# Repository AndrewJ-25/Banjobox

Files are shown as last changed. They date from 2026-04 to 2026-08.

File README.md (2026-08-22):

# Banjobox

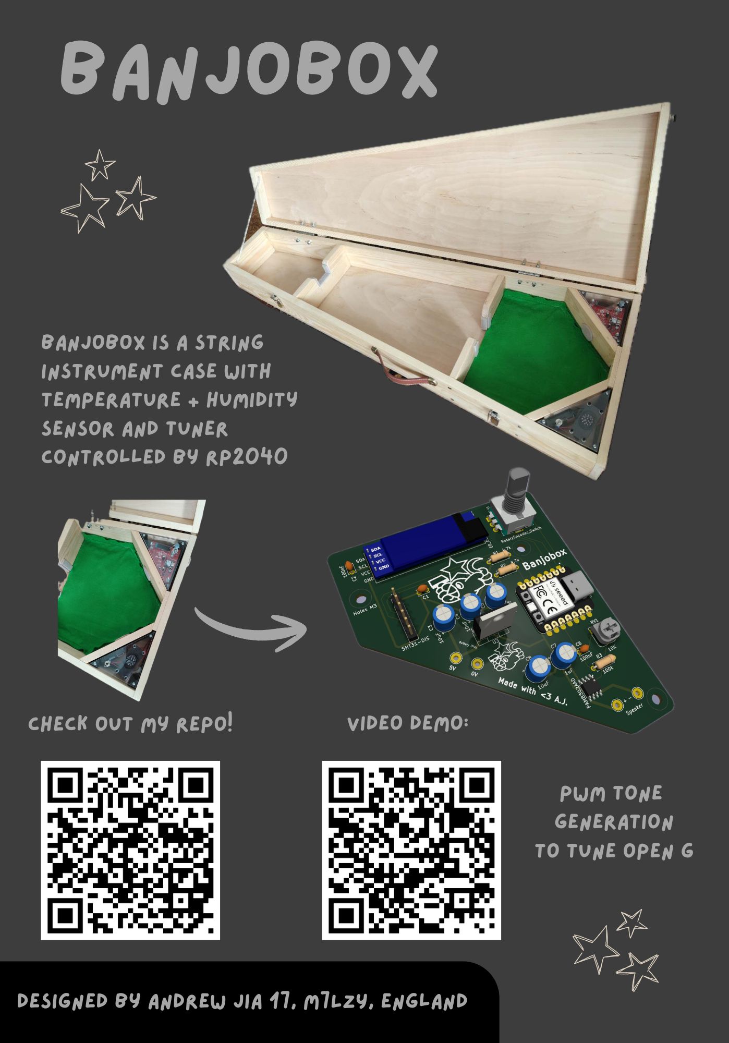
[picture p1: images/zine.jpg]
Zine


Banjobox is a banjo case with a built in tuner and temperature/ humidity sensor. I designed it to store a mountain banjo I made but the case can be modified to accomodate other string instruments.

Purchasing a banjo case is difficult, especially as shape varies a lot. Banjobox is low cost (plywood, softwood timber) and super customiseable!

Banjobox features a Seeed Studios Xiao RP2040 running MicroPython. UI consists of a rotary encoder and 0.91" OLED display. You can select different notes to be played through the speaker to tune your banjo.

Pressing the rotary encoder button switches between monitor mode and tune mode. Monitor mode displays temperature and humidity readings. Tune mode plays a square wave. Turning the knob changes the note played.

Files for 3D printing and laser cutting can be found in the OnShape project linked below.

### Demo
https://www.youtube.com/watch?v=Ie8TWf3fN2Y

### Features
 - Seeed Studios Xiao RP2040
 - SHT31 temp + humidity sensor
 - PAM8302 Class-D amp with 3W 4ohm speaker
 - Powered by 3x AA batteries
 - 0.91 inch OLED display
 - EC11 rotary encoder

## OnShape project
https://cad.onshape.com/documents/49037cb32e4fd0c851c4d81b/w/99bbea41b70cb909ece41dd4/e/4da4cdf8e8884e6941d1b422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

## Schematic
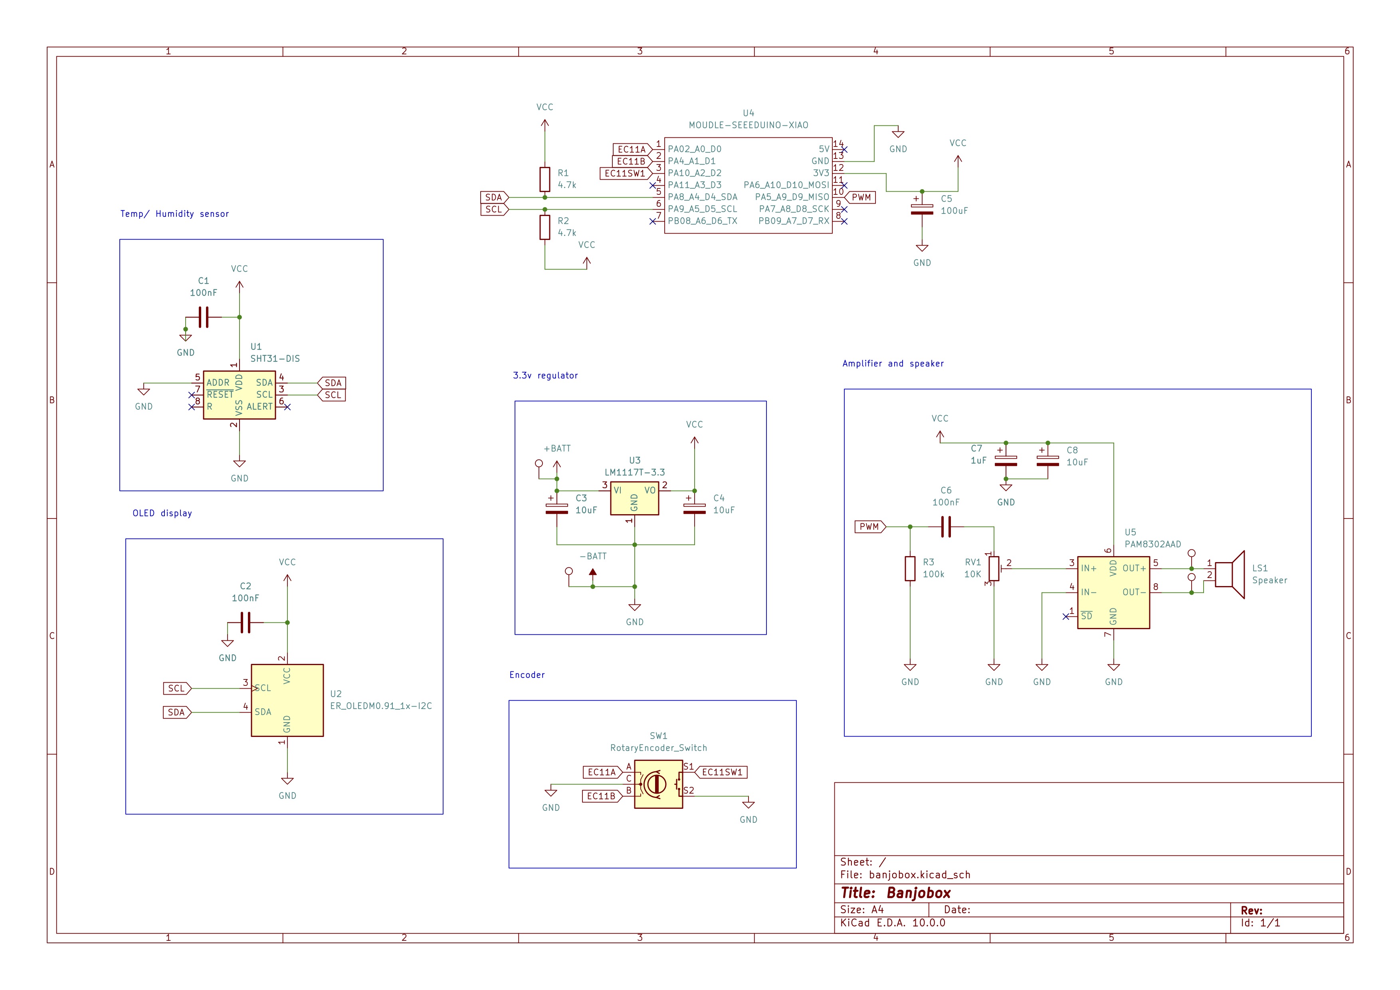
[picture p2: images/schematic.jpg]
Schematic


## Case construction tips
Construction of the case requires minimal woodworking skills and tools. I reccomend using some wood screws rather than relying on glue alone. A full set of plans can be found in the production folder.

### General
 - Add felt padding where appropriate (including this in the CAD model was impractical). The green blocks on the lid can be made by wrapping foam with felt.
   
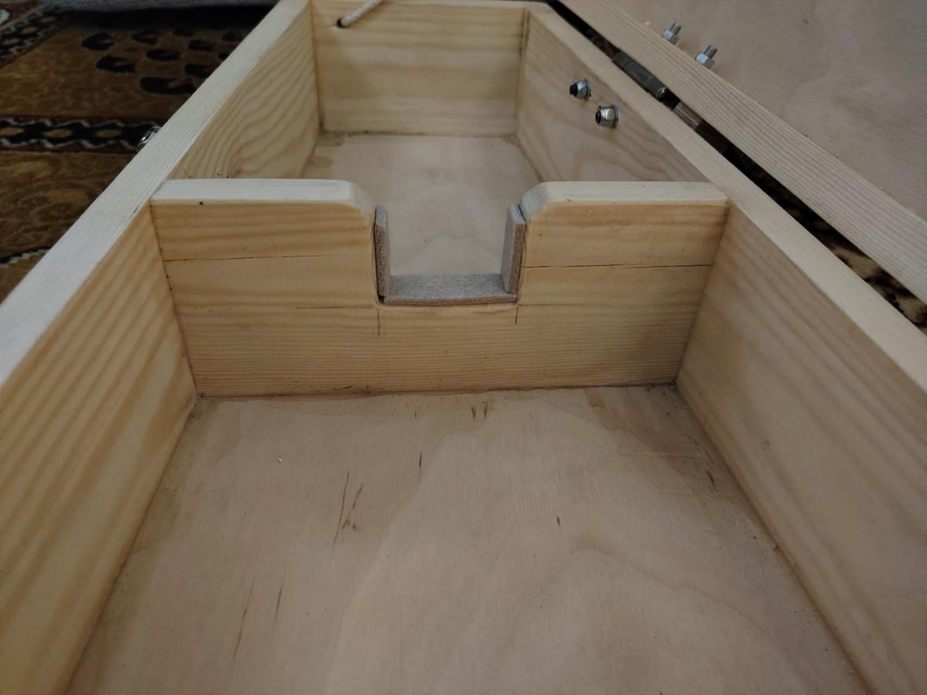
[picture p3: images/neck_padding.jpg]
padding
   
 - Heel supports can be reinforced with metal brackets or dowels
 - Remember to cut holes to run wires!
 - Hold battery holder in place with velcro.
 - SHT31 breakout board to be fixed inside battery compartment with sticky foam. Speaker vents will ensure good airflow.
 - Electronics parts are held in place by two acrylic covers. Use long M3 bolts or threaded rod to mount the PCB.

### 3D printing
 - The PCB cover and speaker/ battery cover are each supported by three 3D printed columns
 - Use M3 heatset inserts
 - Glue in place

### Laser cutting
 - Laser cut PCB and spekeaker/ battery covers from clear acrylic
 - Recommended 4mm but exact thickness is unimportant

Remember to cut wire holes in the side supports! See below:
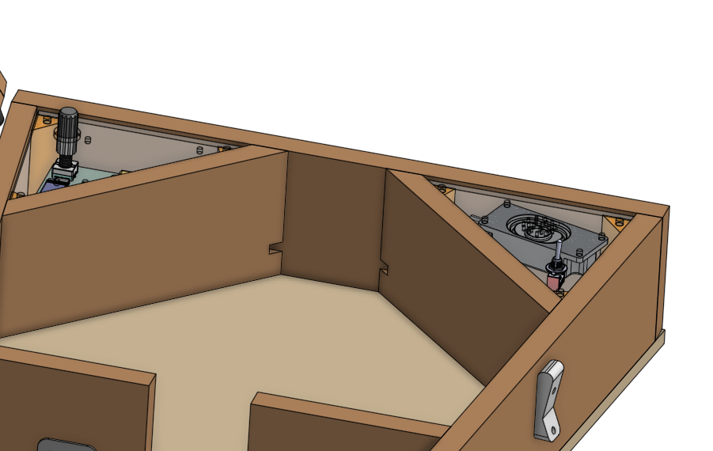
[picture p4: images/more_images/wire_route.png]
Wire run


### Note regarding PCB
- In the final product, the external voltage regulator and accompanying capacitors were omitted in favour of the XIAO's onboard voltage regulator.

## Images
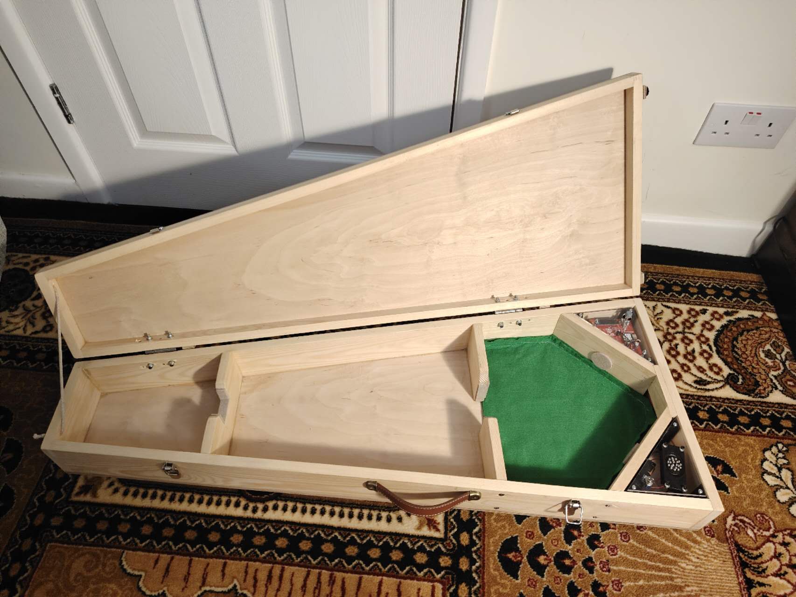
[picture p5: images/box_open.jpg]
banjobox

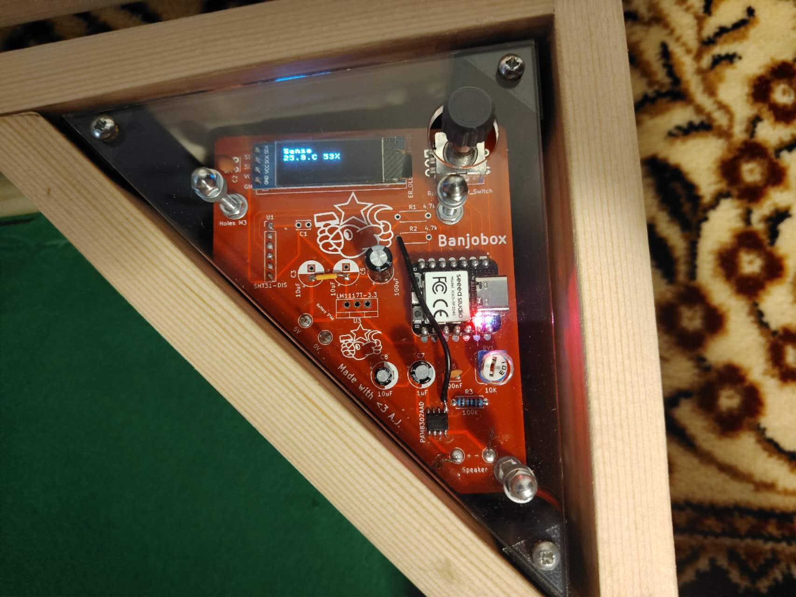
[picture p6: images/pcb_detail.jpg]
pcb

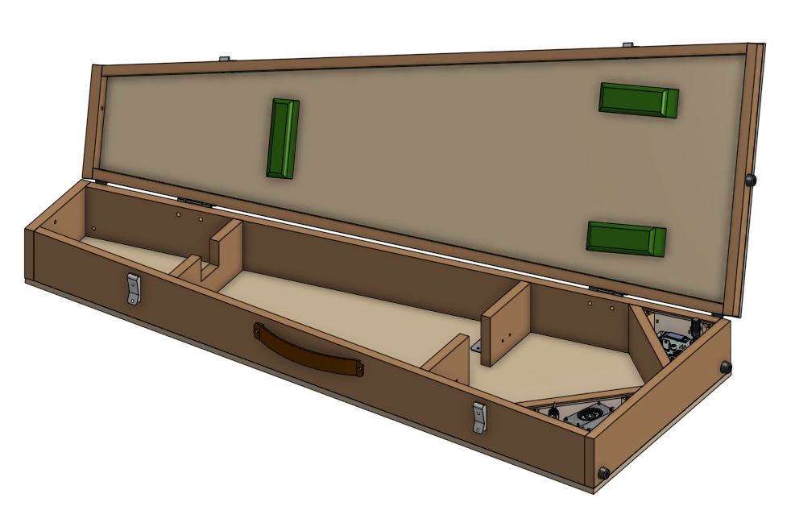
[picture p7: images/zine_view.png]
render

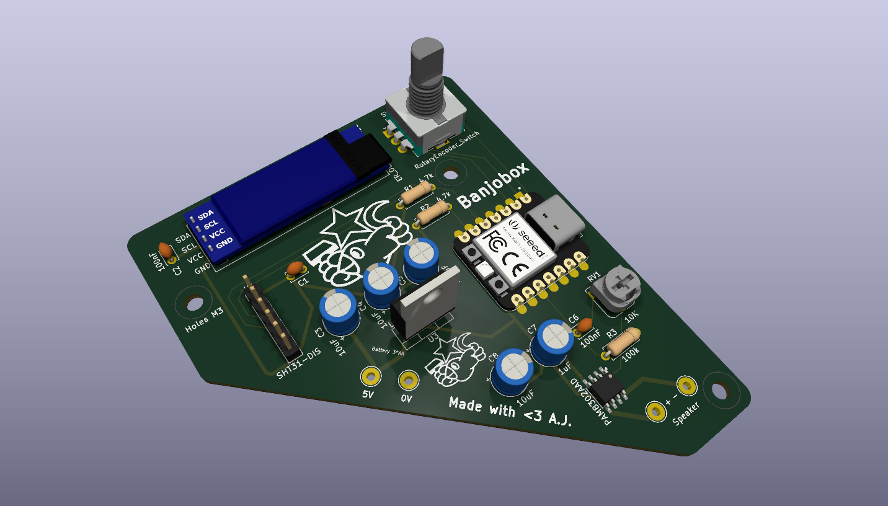
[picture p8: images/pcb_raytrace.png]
prcb render


## BOM
NOTE: Links are suggestions only. Some parts are ubiquitous and purchasing online would be impractical not to mention expensive. I'm from the UK hence some links might not work if you live overseas. Prices may vary.
| Quantity | Item | Cost/£ | Link |
|---|---|---|---|
| 1 | Seeed Studios Xiao RP2040 | 3.90 | https://thepihut.com/products/seeed-xiao-rp2040 |
| 1 | PCB | 5.00 | https://jlcpcb.com/ |
| 1 | 0.91 inch OLED | 3.80 | https://www.aliexpress.com/item/1005006365845676.html |
| 1 | SHT31 breakout board | 1.57 | https://www.aliexpress.com/item/32695064184.html |
| - | Components | 10.00 | https://www.digikey.co.uk/ |
| 1 | 3W speaker | 3.40 | https://thepihut.com/products/mono-enclosed-speaker-3w-4-ohm |
| 1 | Toggle switch | 1.67 | https://www.digikey.co.uk/en/products/detail/cit-relay-and-switch/ANT11SEBQE/12503360 |
| 1 | 3xAA battery holder | 1.99 | https://www.ebay.co.uk/itm/358406972409?_skw=3+x+aa+battery+holder |
| 6 | 3D printed parts | 2.00 | https://jlcpcb.com/ |
| 2 | laser-cut acrylic | 0.50 | https://jlcpcb.com/ |
| 6 | Heatset insert | 2.89 | https://www.ebay.co.uk/itm/314297471901 |
| 13 | M3 screw | 7.59 | https://www.ebay.co.uk/itm/305743217020 |
| 7 | M3 nut | 3.38 | https://www.ebay.co.uk/itm/167673257973 |
| - | Wood screws | 7.74 | https://www.ebay.co.uk/itm/277661008745?_skw=wood+screws |
| - | 15mm timber | 16.00 | https://www.homedepot.com/p/Waddell-Project-Board-24-in-x-4-in-x-0-5-in-Unfinished-S4S-Poplar-Hardwood-w-No-Finger-Joints-Ideal-for-DIY-Shelving-PB19418/329189316 |
| 1 | Plywood 9mm | 30.00  | https://www.ebay.co.uk/itm/257438787345?_skw=9mm+plywood |
| 2 | Hinges | 1.97 | https://www.ebay.co.uk/itm/222426341432 |
| 2 | Hook and latch | 3.60 | https://www.ebay.co.uk/itm/168179187930 |
| 1 | Handle | 4.20 | https://www.ebay.co.uk/itm/306436283287 |
| 11 | Rubber feet | 3.29 | https://www.ebay.co.uk/itm/173200464234 |
| - | Foam padding | 10.99  | https://www.ebay.co.uk/itm/112490209816 |
| - | Felt padding | 6.25 | https://www.ebay.co.uk/itm/188091406494 |
|TOTAL: | | 131.73 | |

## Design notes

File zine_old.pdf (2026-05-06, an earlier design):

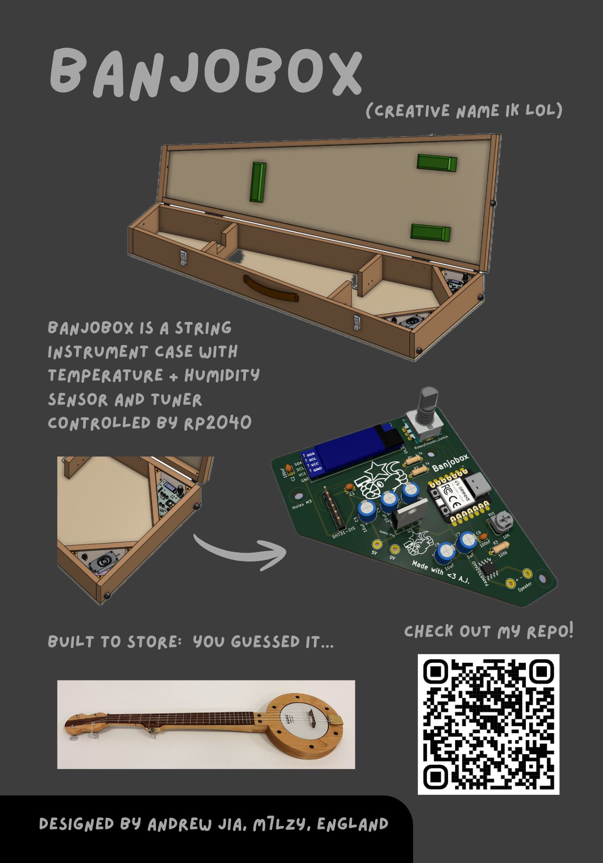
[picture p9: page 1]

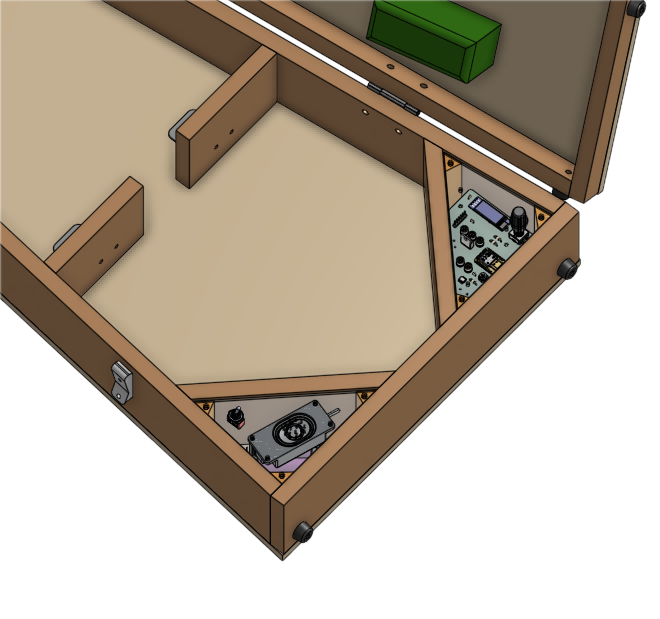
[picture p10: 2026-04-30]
images/more_images/zine_detail Background Removed.png

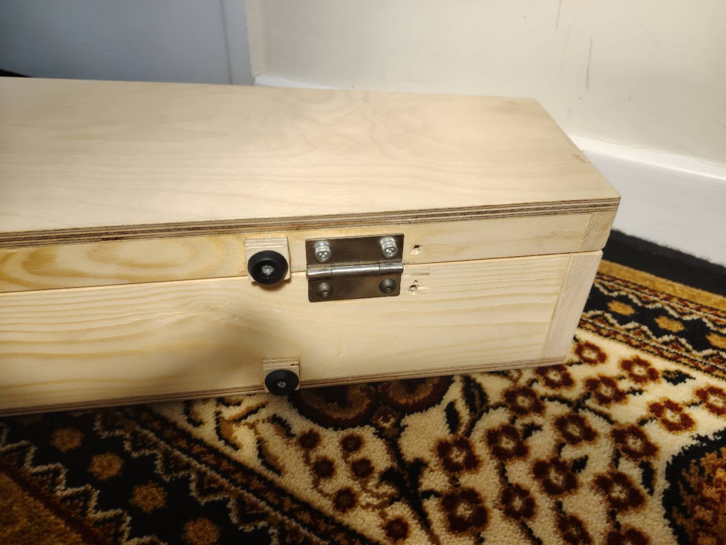
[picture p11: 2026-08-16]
images/hinge.jpg

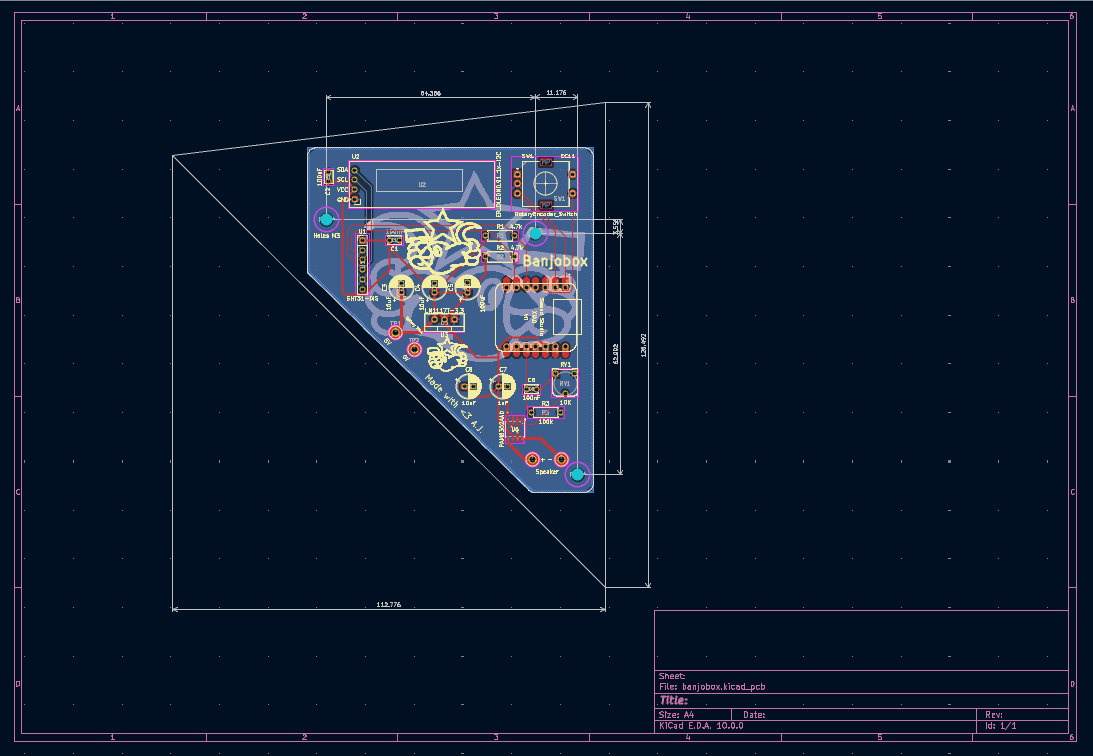
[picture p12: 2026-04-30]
images/banjobox_pcb.png

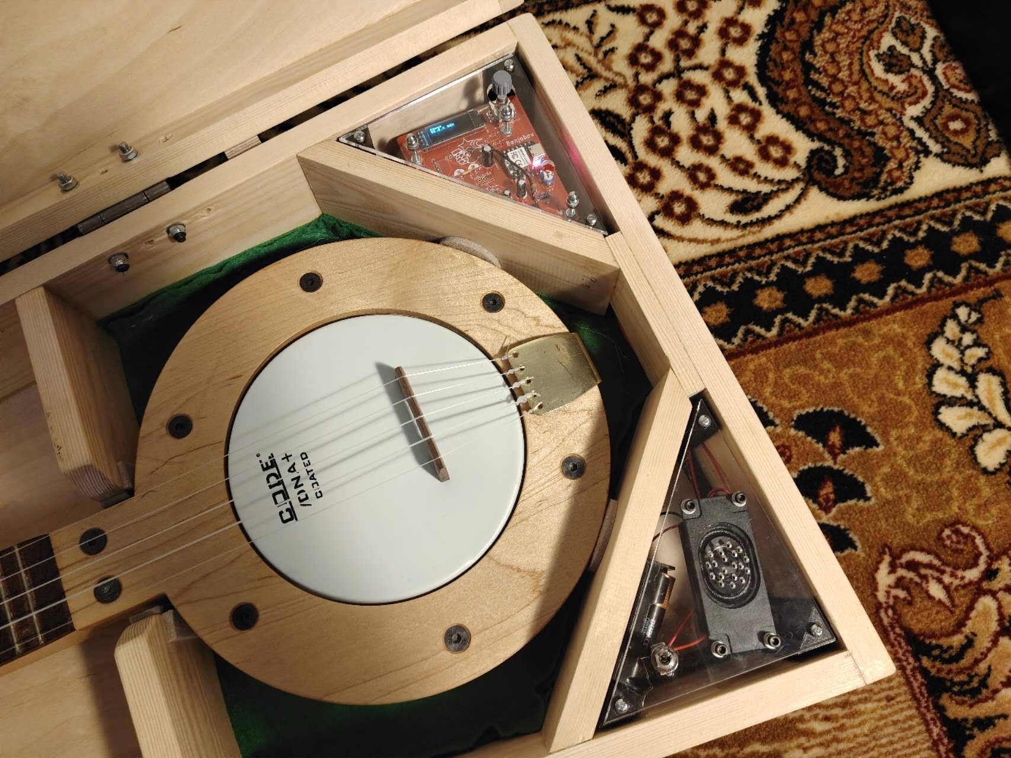
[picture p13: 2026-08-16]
images/banjo_body.jpg

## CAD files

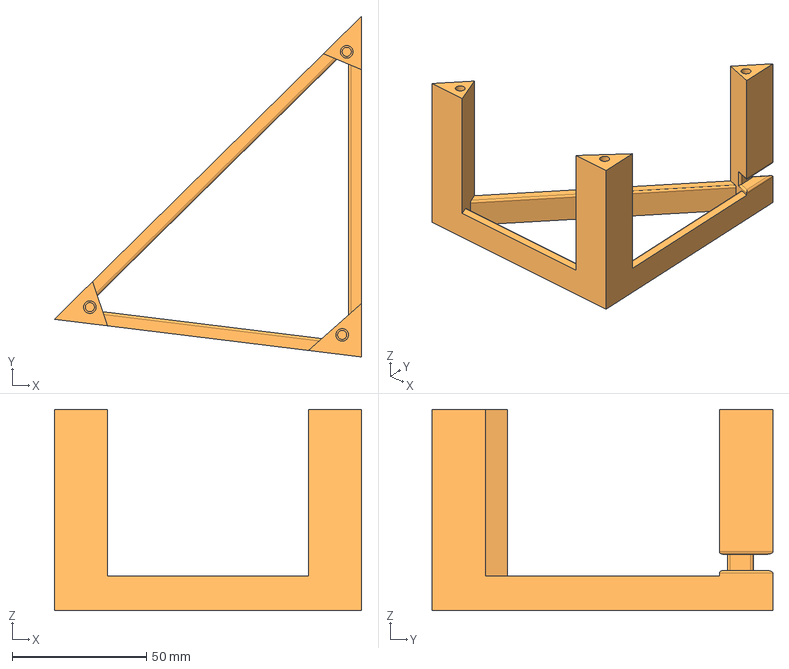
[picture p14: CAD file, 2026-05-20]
production/3d_print/step/speaker_cover_mounts.step
114.4 x 126.9 x 75.0 mm

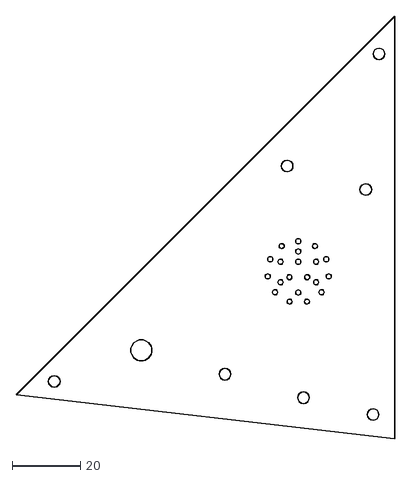
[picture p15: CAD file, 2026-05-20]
production/acrylic/dxf/speaker_cover.dxf
110.5 x 123.4

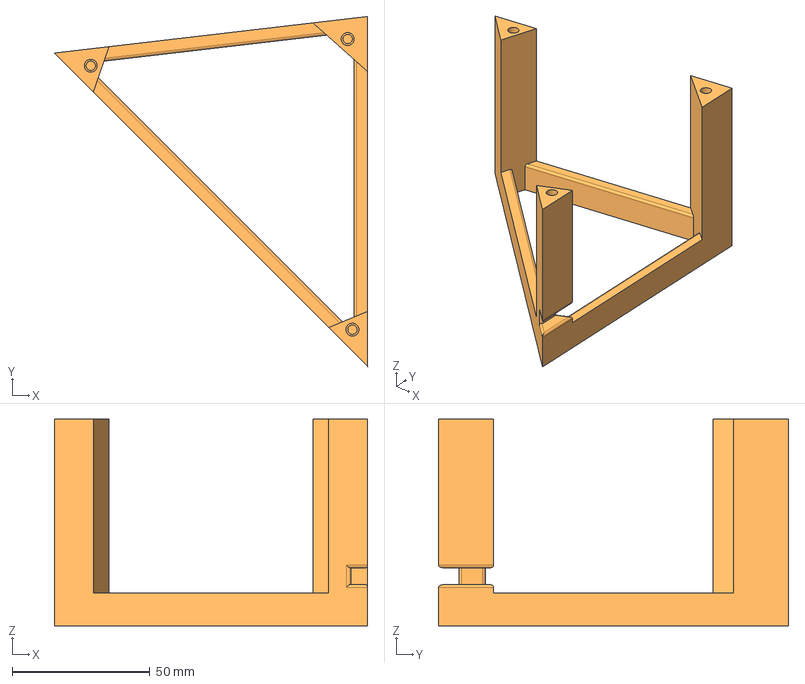
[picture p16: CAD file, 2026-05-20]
production/3d_print/step/pcb_cover_mounts.step
113.7 x 126.9 x 75.0 mm

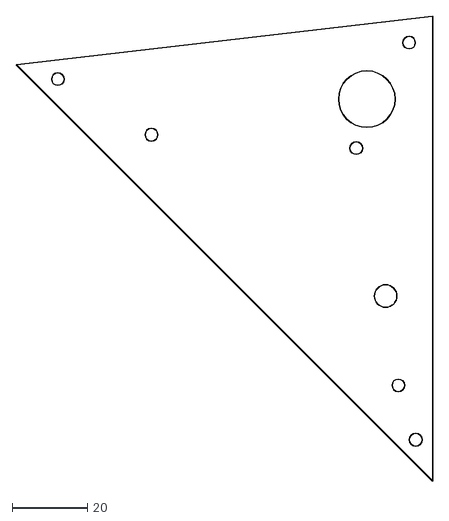
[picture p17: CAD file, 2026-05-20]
production/acrylic/dxf/pcb_cover.dxf
110.5 x 123.4

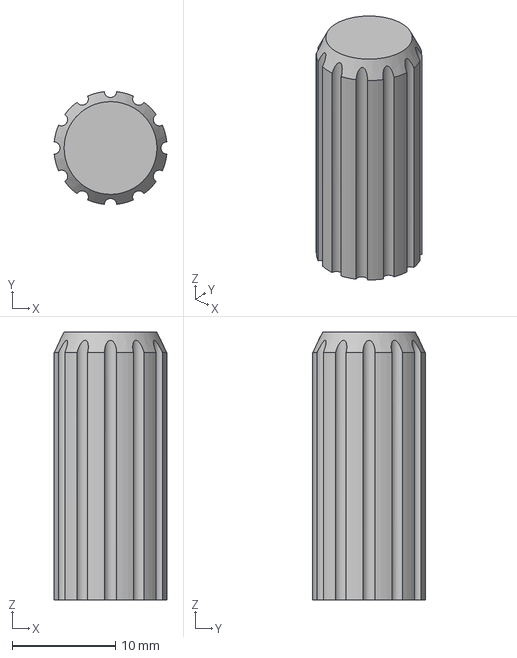
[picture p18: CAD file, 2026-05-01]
production/3d_print/step/knob.step
10.9 x 10.9 x 26.0 mm

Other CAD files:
production/3d_print/stl/knob.stl
production/3d_print/stl/pcb_cover_mounts.stl
production/3d_print/stl/speaker_cover_mounts.stl
production/acrylic/dwg/pcb_cover.dwg
production/acrylic/dwg/speaker_cover.dwg
production/acrylic/pcb_cover.dxf
production/acrylic/speaker_cover.dxf

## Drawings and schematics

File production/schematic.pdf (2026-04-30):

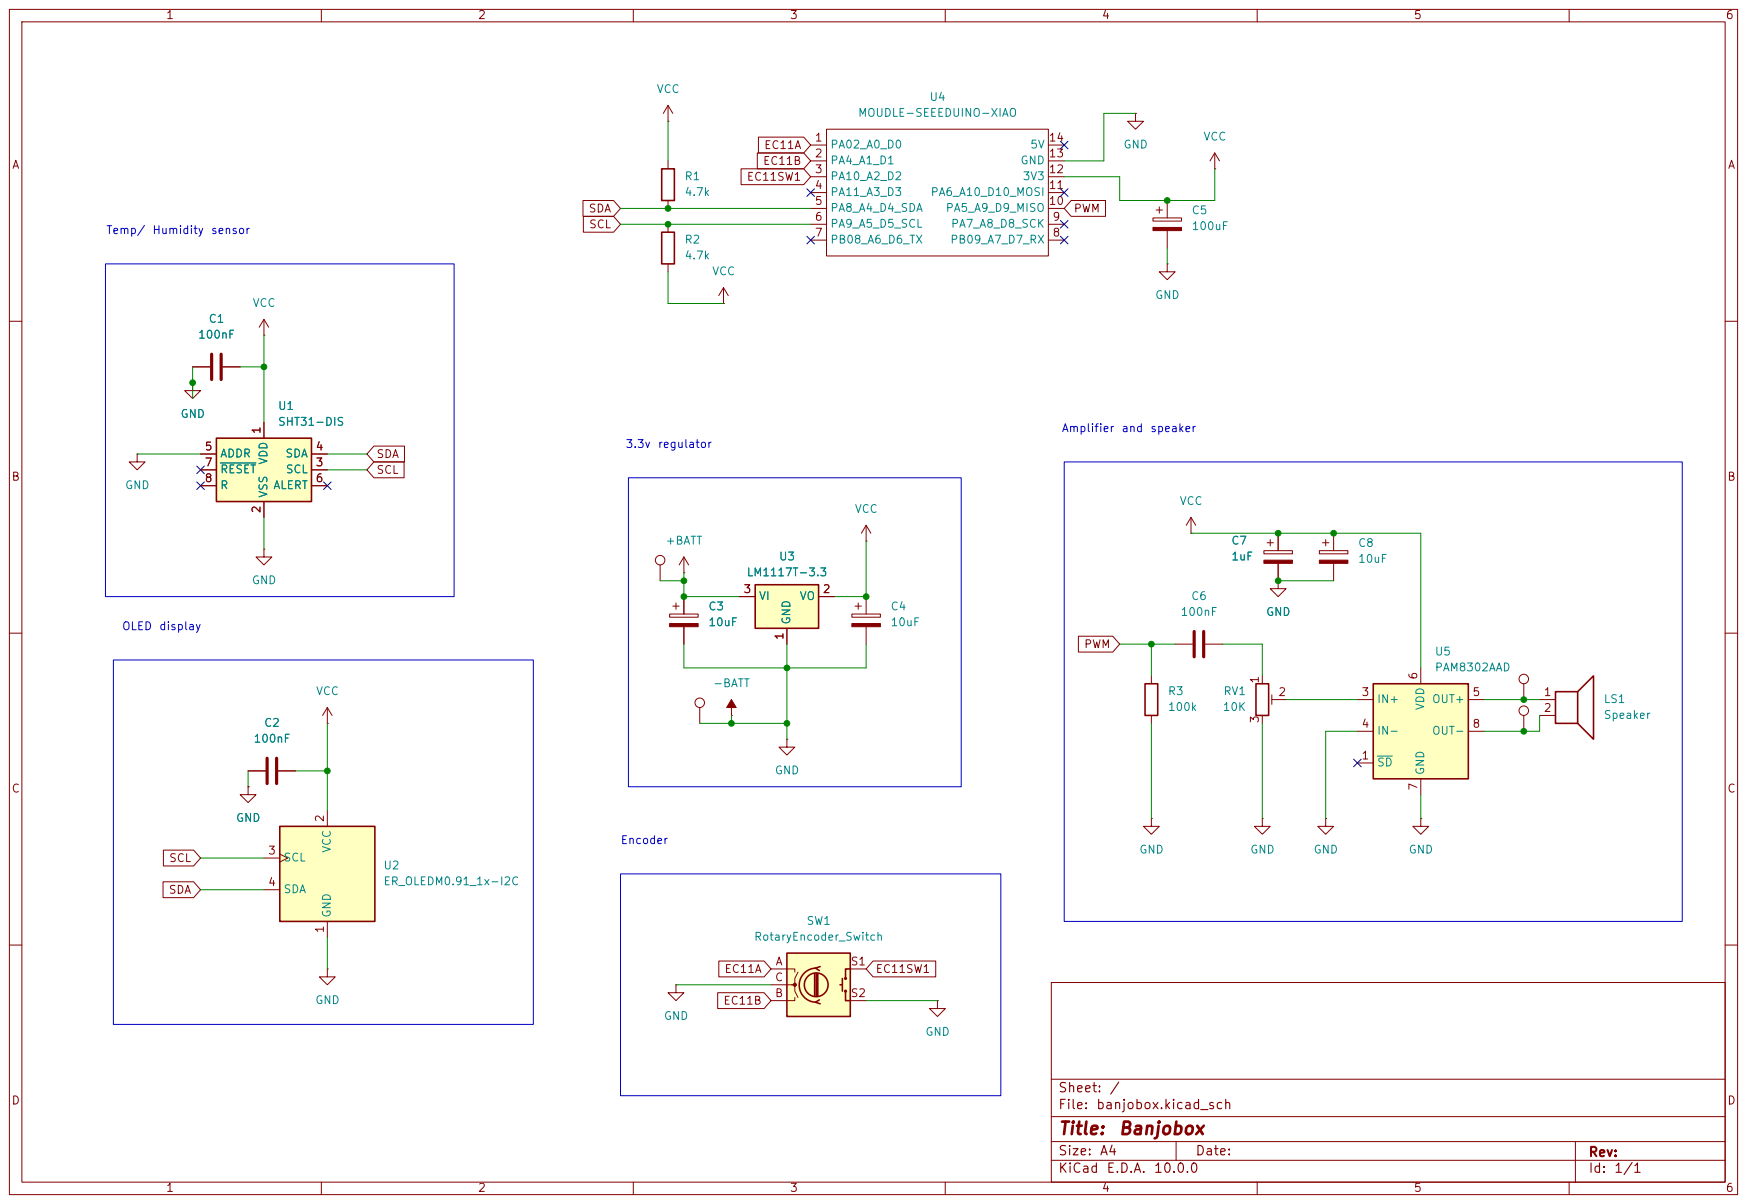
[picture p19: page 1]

Size: A4 | Rev:
KiCad E.D.A. 10.0.0 | Id: 1/1

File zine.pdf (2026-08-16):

# Banjobox

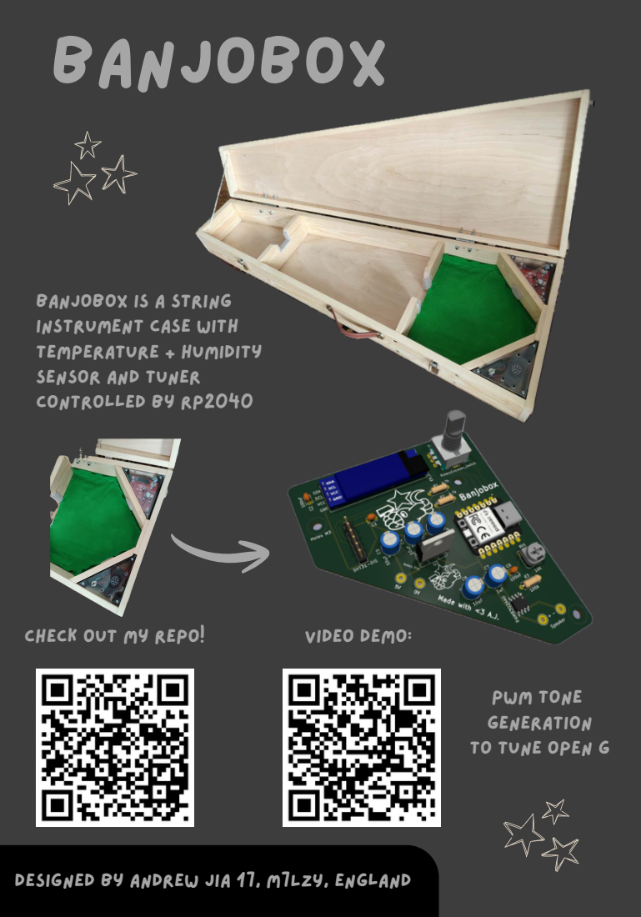
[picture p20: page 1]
Check out my repo!; video demo:

Banjobox is a string
instrument case with
temperature + humidity
sensor and tuner
controlled by RP2040

PWM tone
generation
to tune open g

designed by Andrew Jia 17, M7LZY, England

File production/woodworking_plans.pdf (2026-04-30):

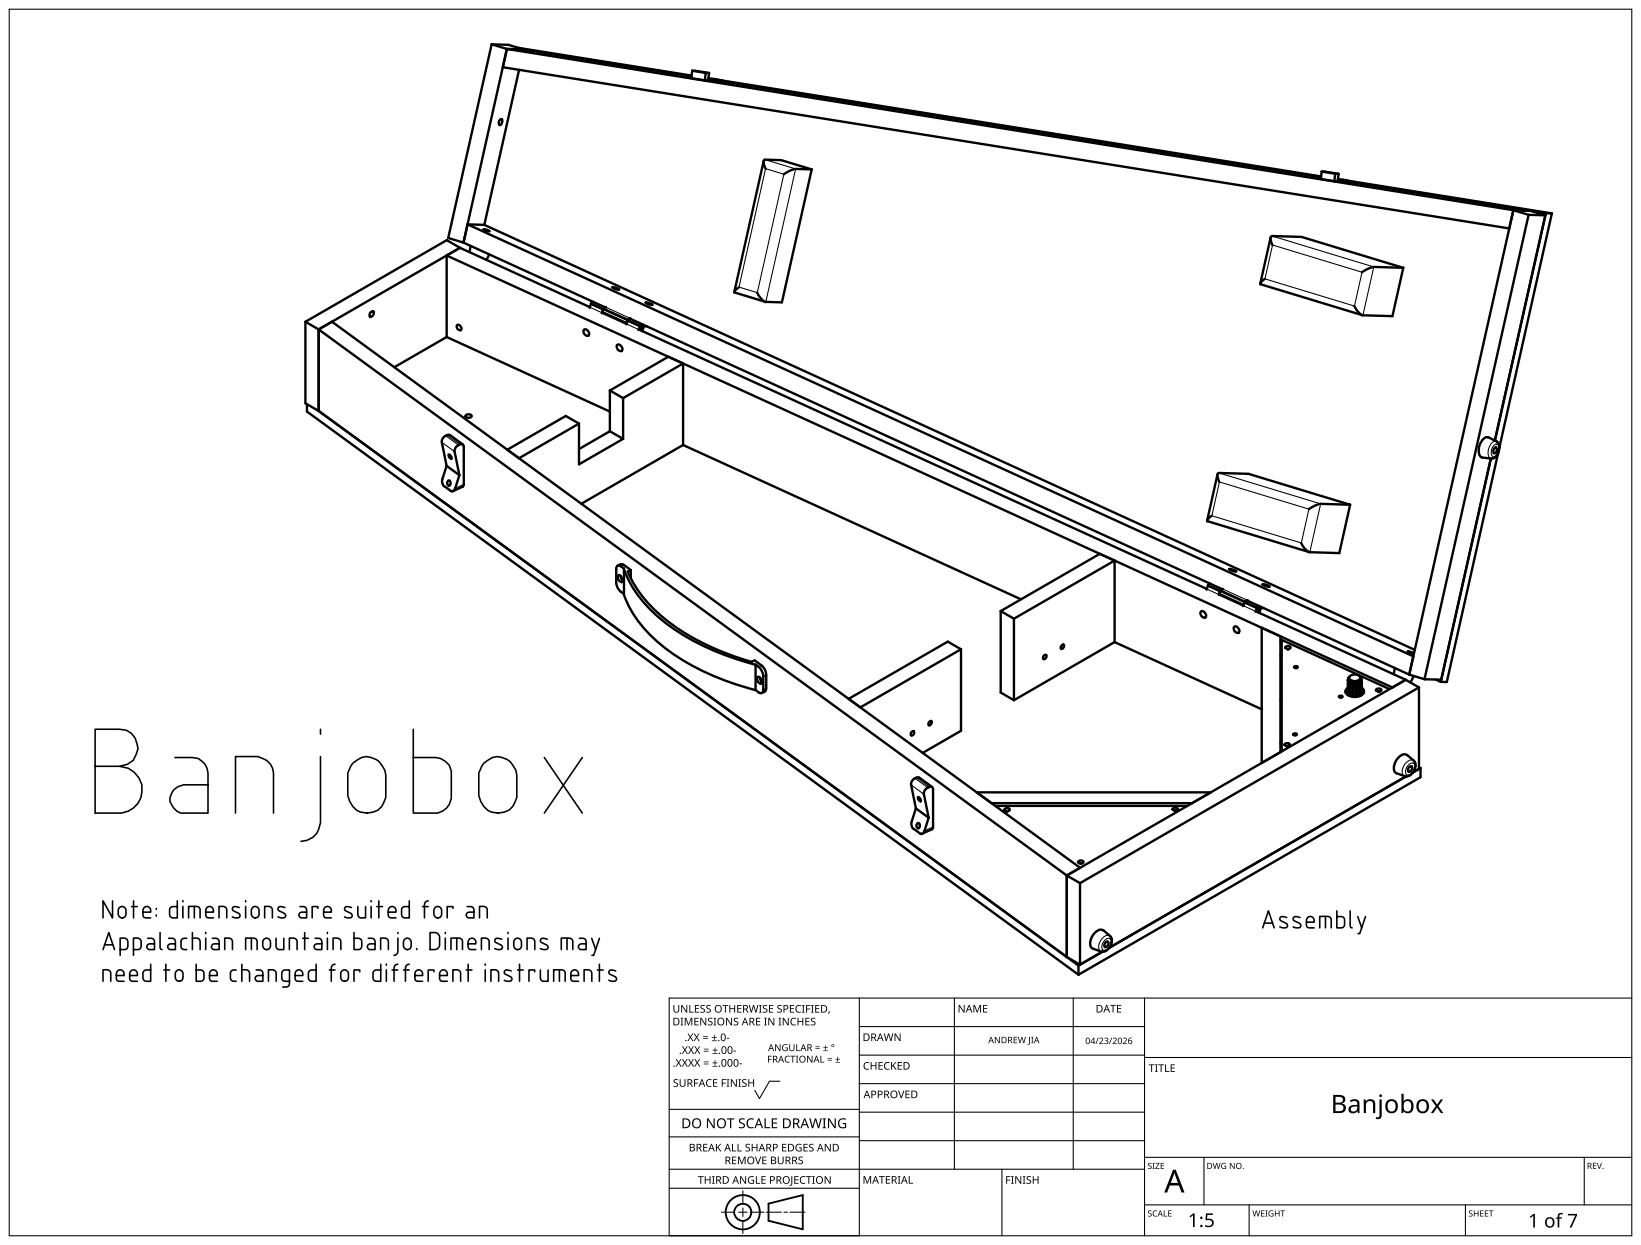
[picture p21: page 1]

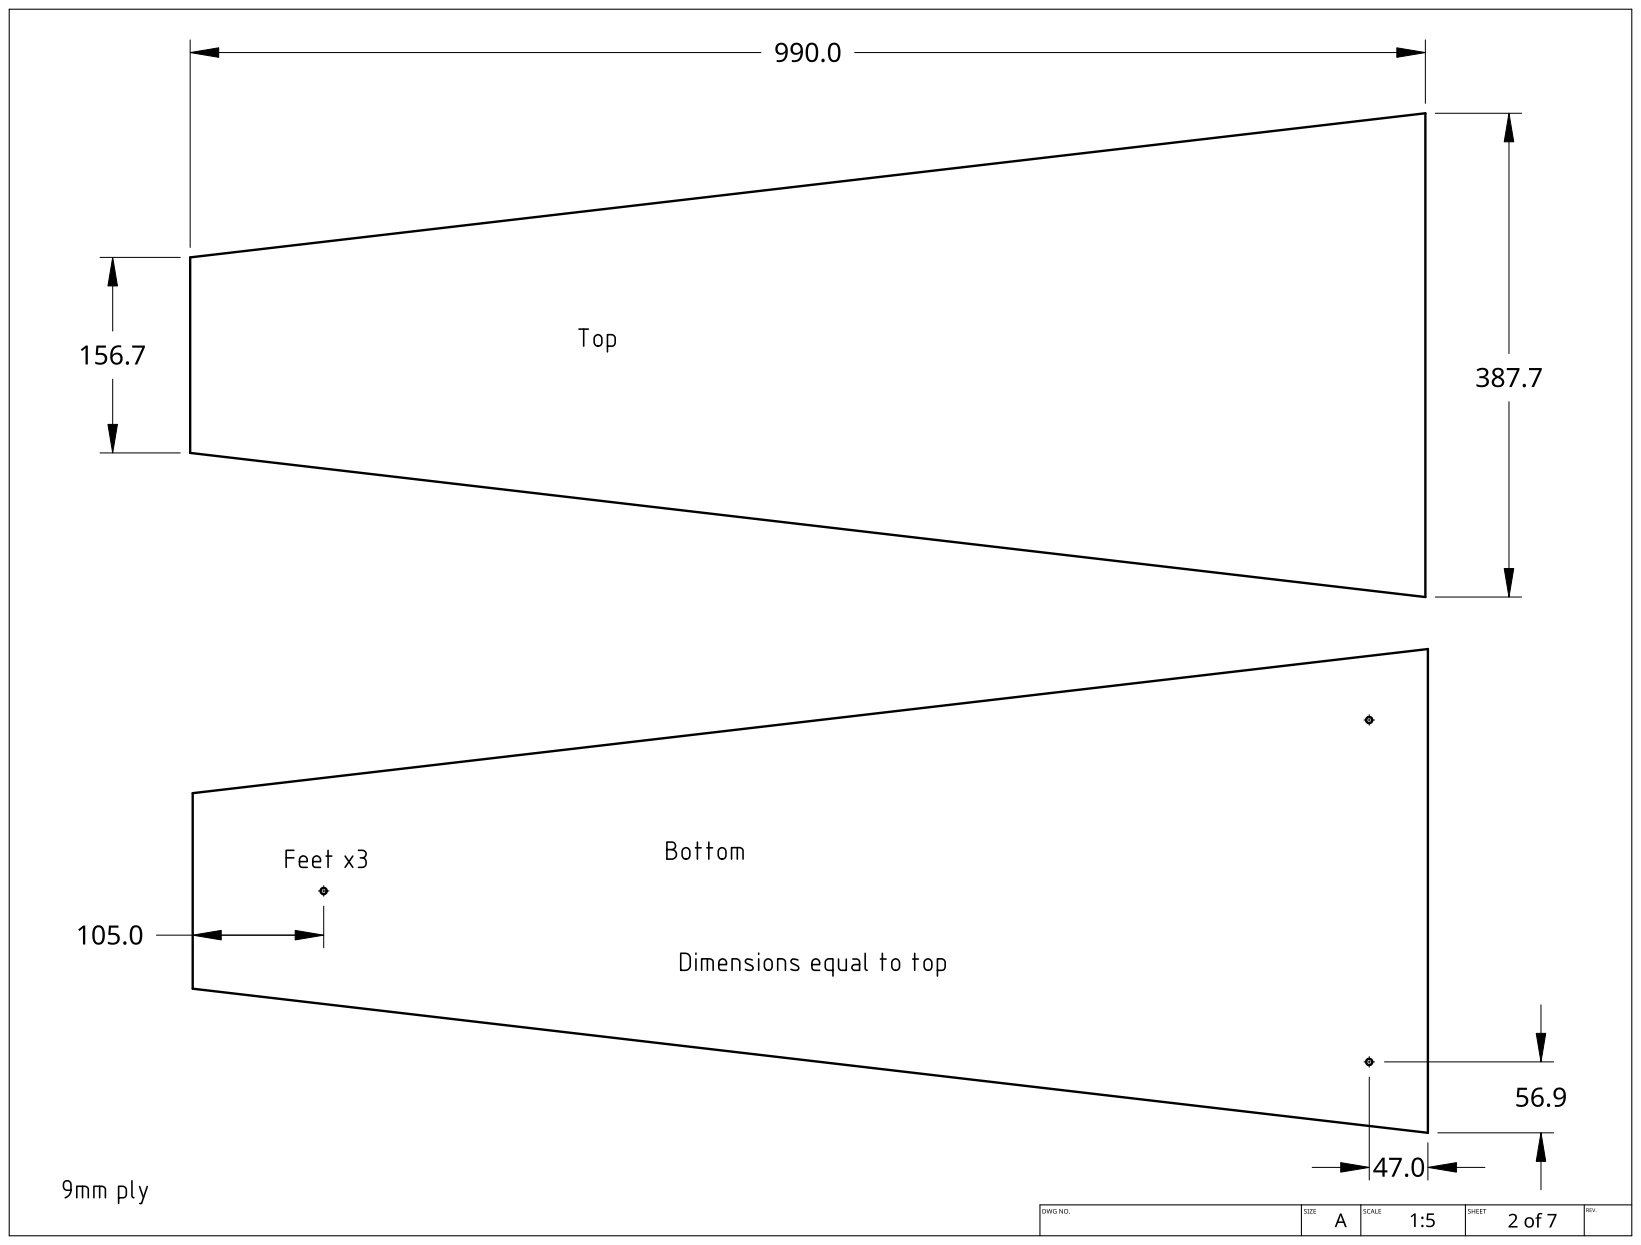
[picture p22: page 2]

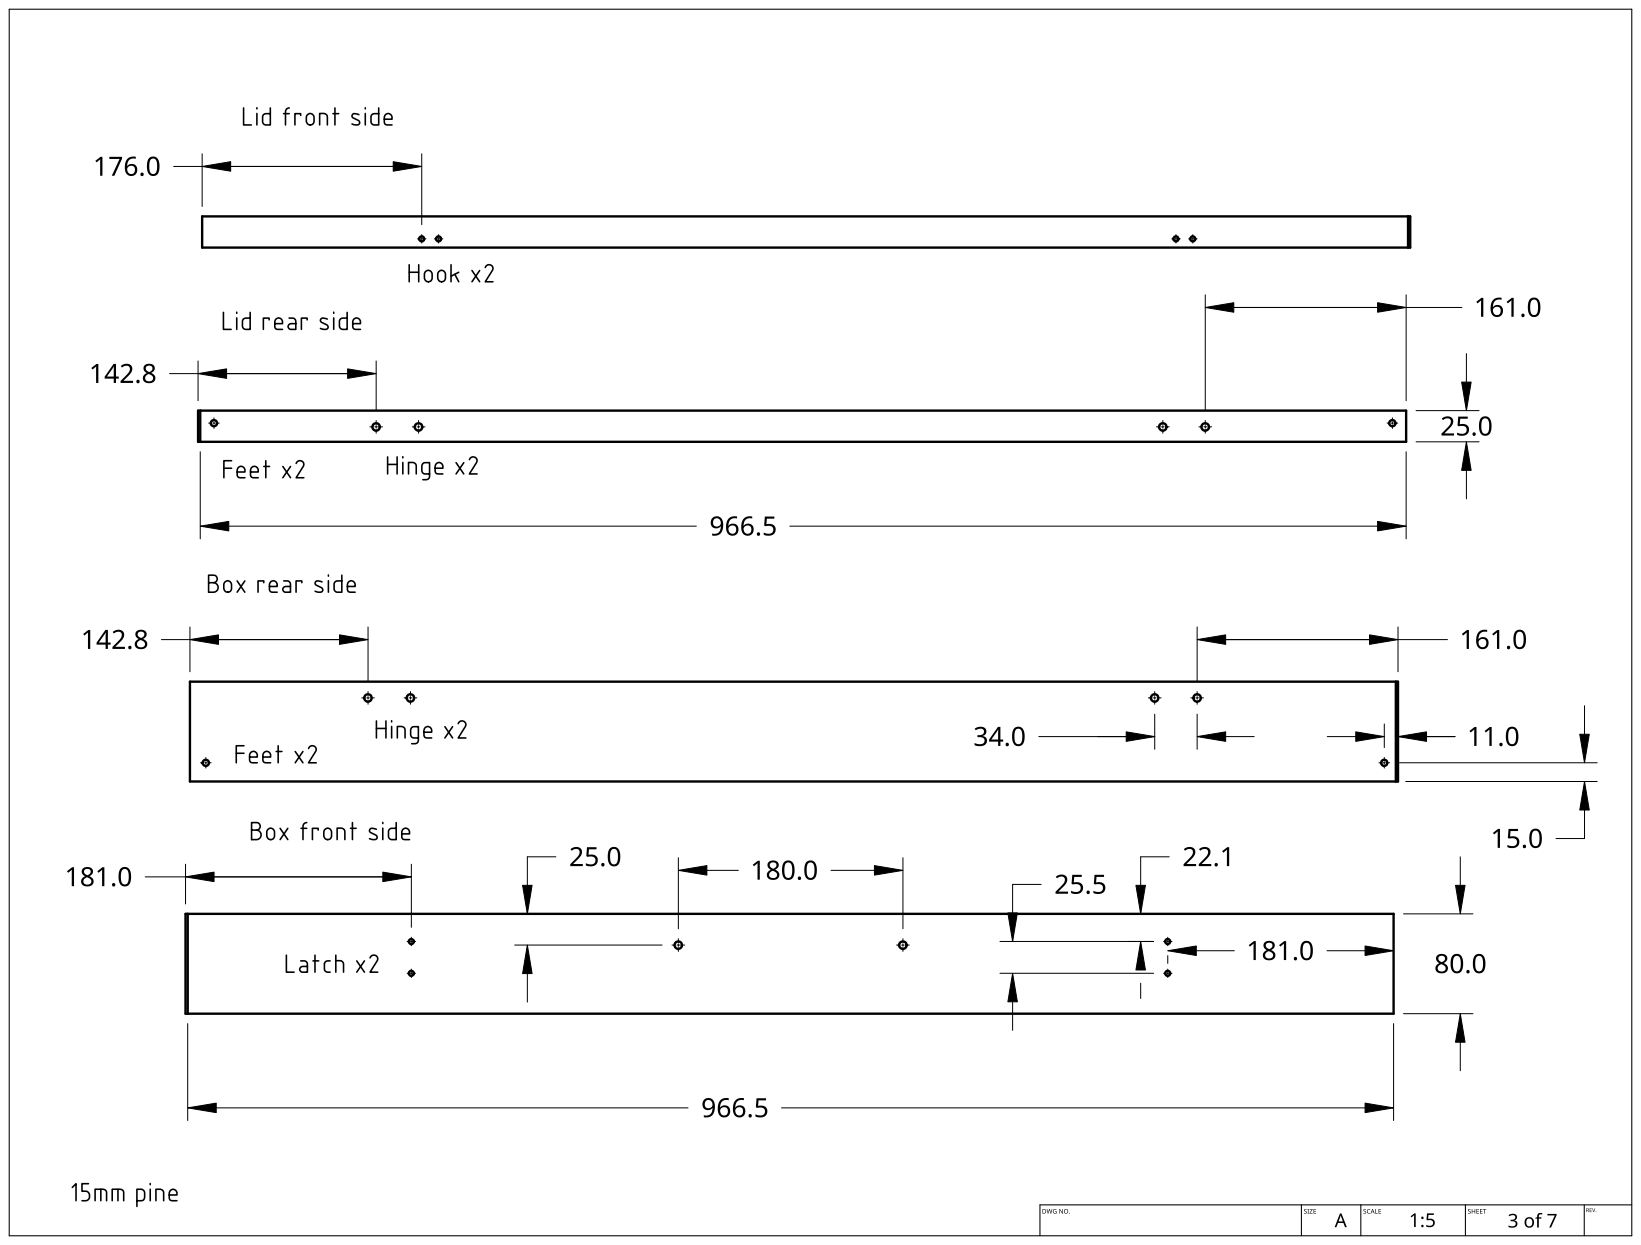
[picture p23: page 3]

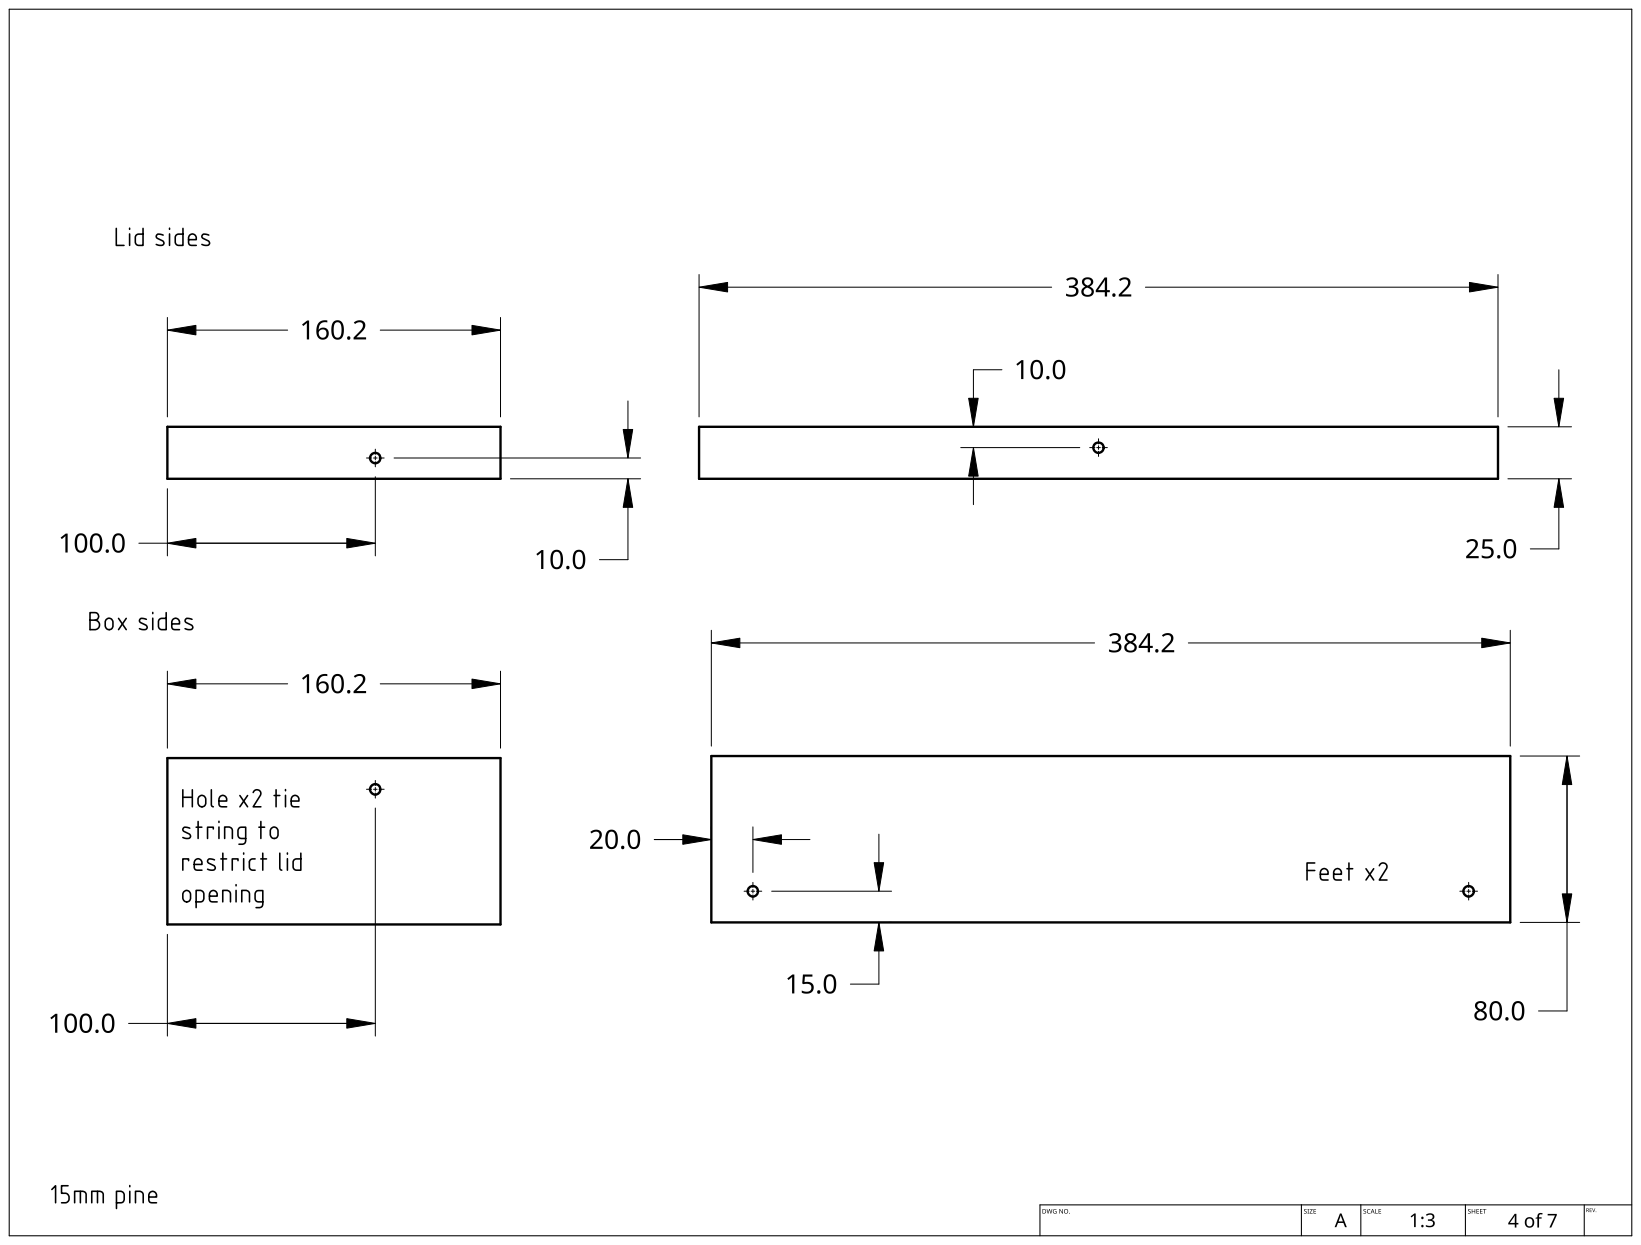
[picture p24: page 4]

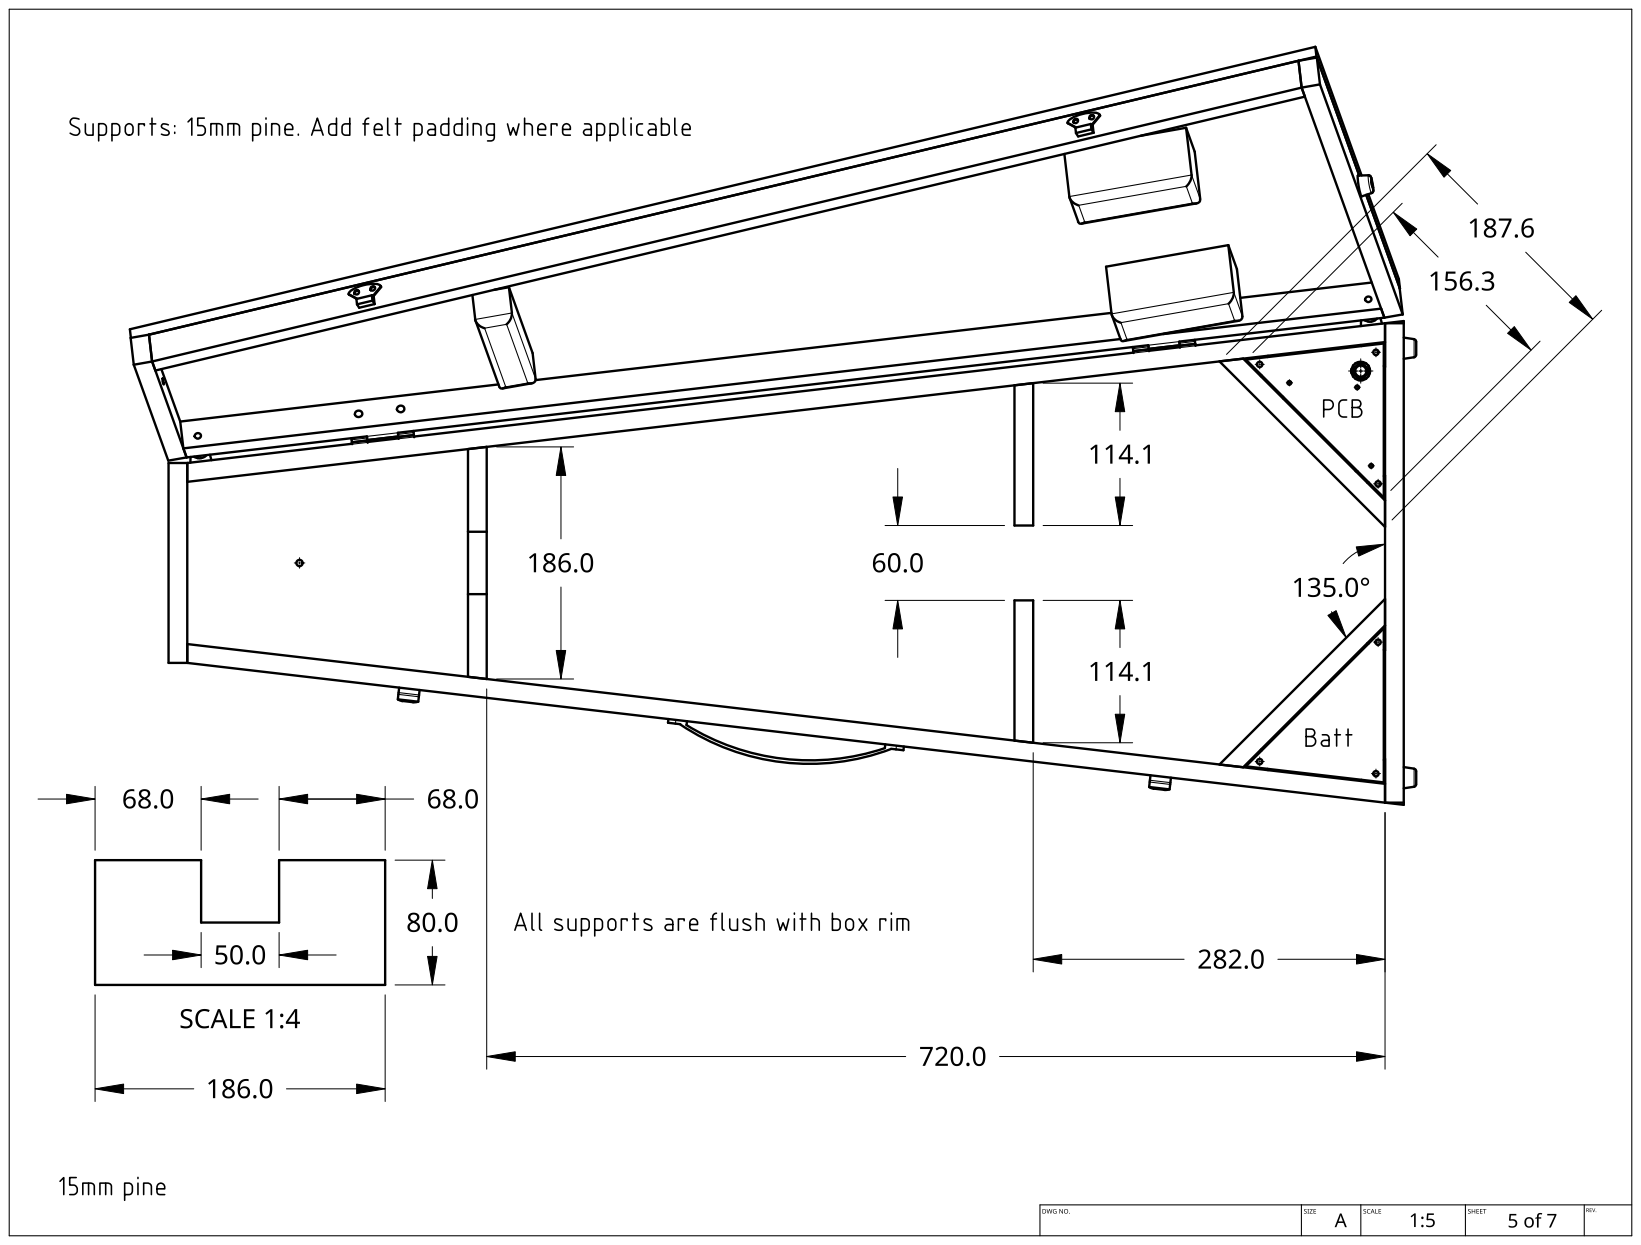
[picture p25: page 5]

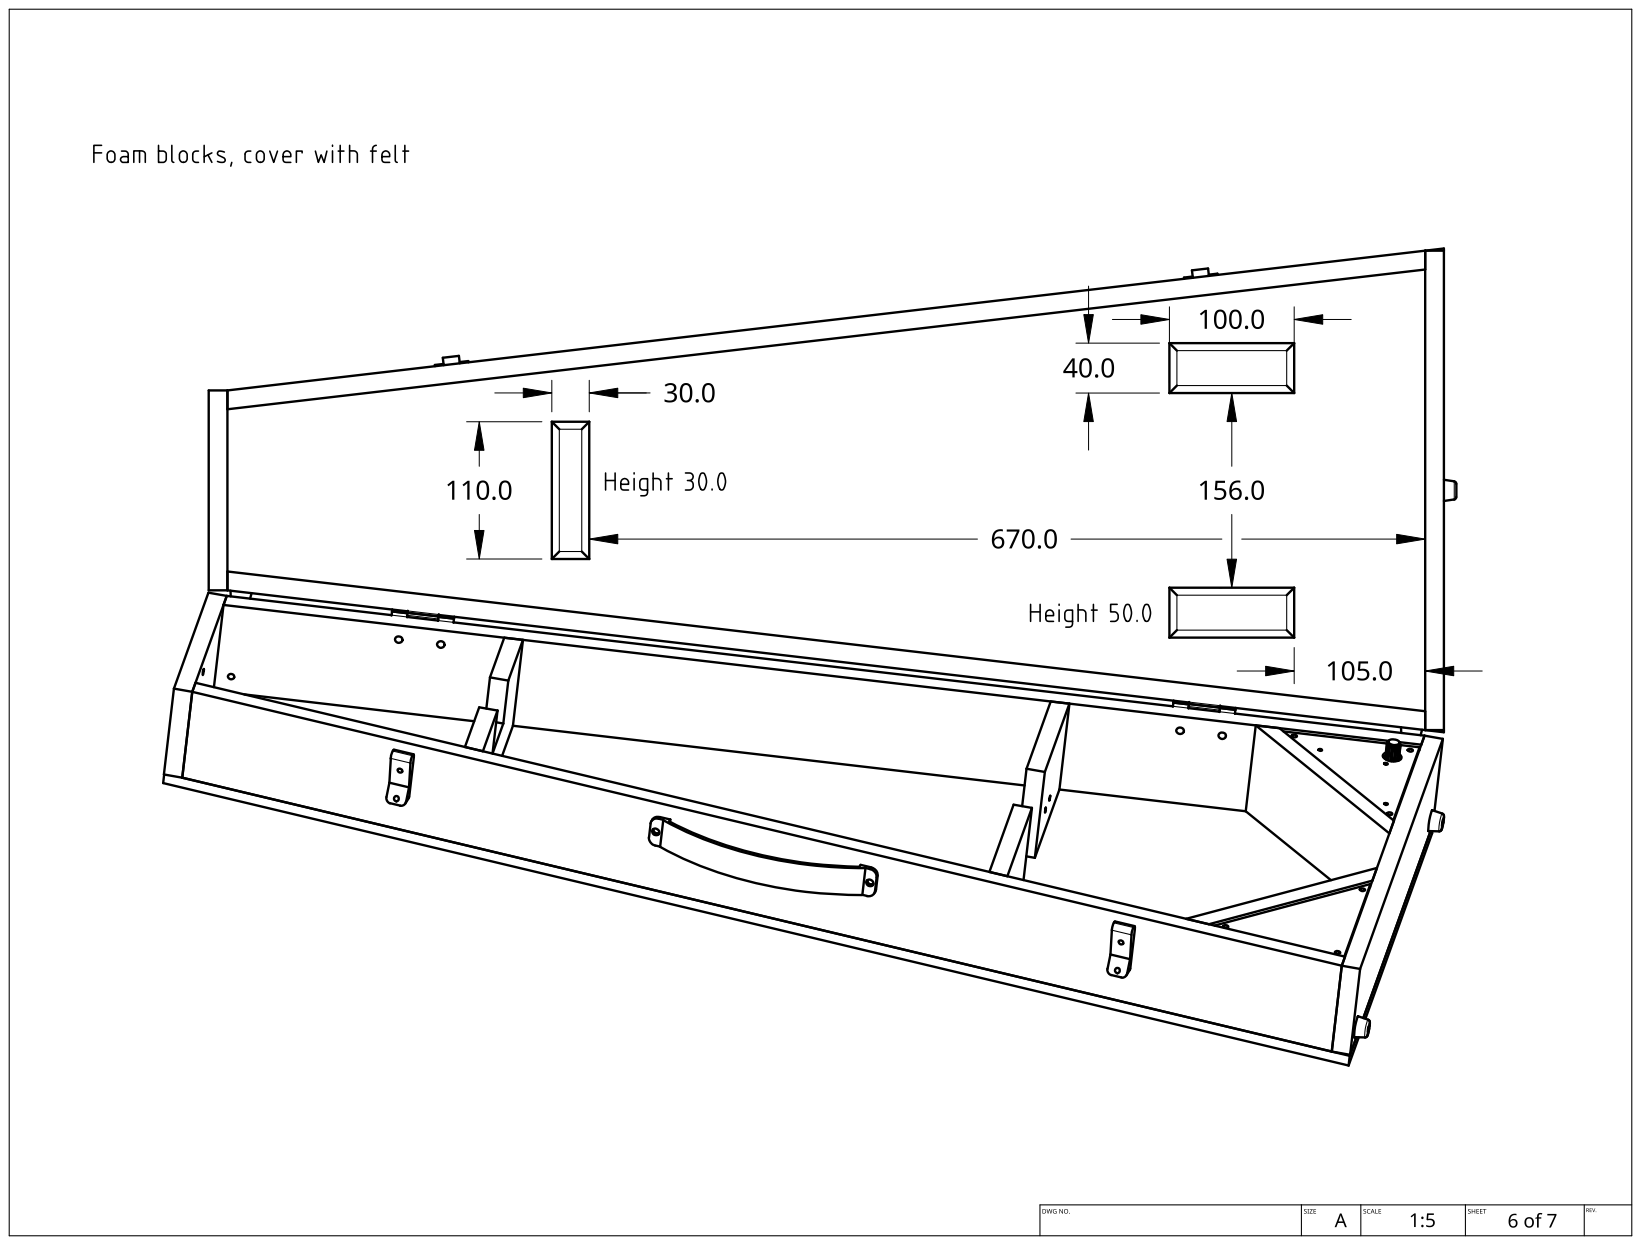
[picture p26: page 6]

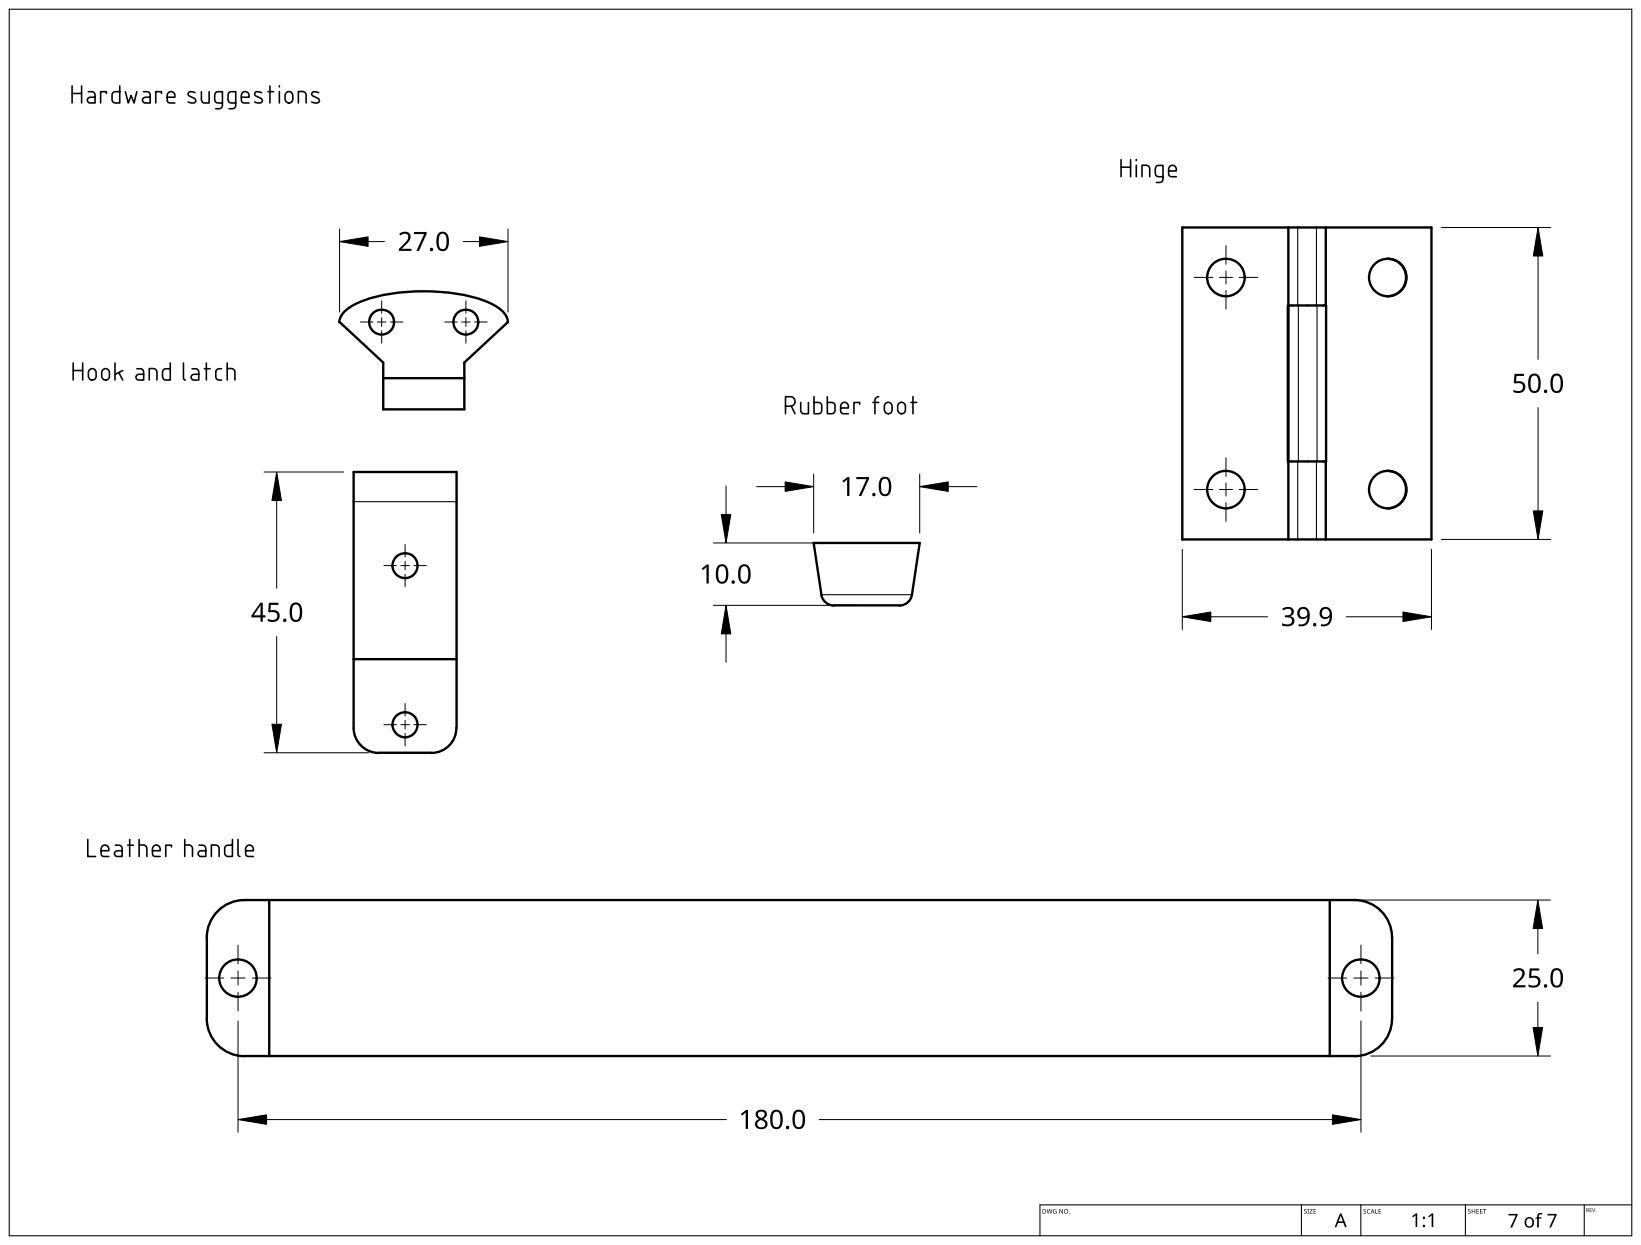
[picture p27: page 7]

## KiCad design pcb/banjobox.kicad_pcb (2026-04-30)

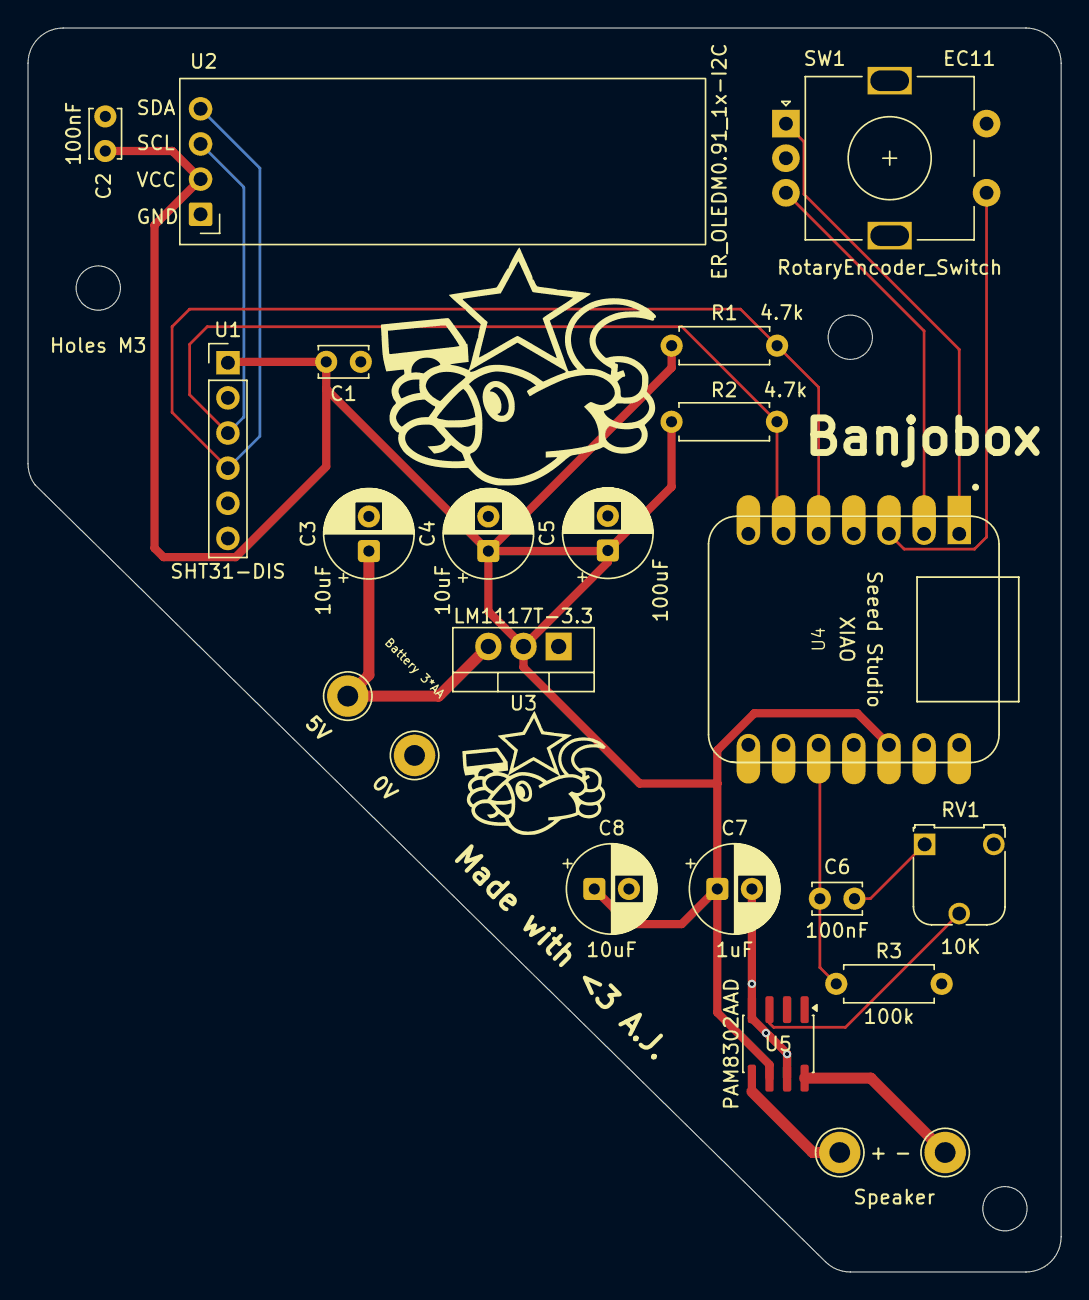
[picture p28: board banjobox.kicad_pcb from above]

Board: 2 copper layers, 74.7 x 89.9 mm, 22 parts (0 on the bottom side), 13 nets.

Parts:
C1, C2, C6: 100nF; C_Disc_D3.4mm_W2.1mm_P2.50mm
C3, C4, C8: 10uF; CP_Radial_D6.3mm_P2.50mm
C5: 100uF; CP_Radial_D6.3mm_P2.50mm
C7: 1uF; CP_Radial_D6.3mm_P2.50mm
R1, R2: 4.7k; R_Axial_DIN0207_L6.3mm_D2.5mm_P7.62mm_Horizontal
R3: 100k; R_Axial_DIN0207_L6.3mm_D2.5mm_P7.62mm_Horizontal
RV1: 10K; Potentiometer_Runtron_RM-065_Vertical
SW1: RotaryEncoder_Switch; RotaryEncoder_Alps_EC11E-Switch_Vertical_H20mm
TP1, TP2, TP3, TP4: TestPoint; TestPoint_THTPad_D3.0mm_Drill1.5mm
U1: SHT31-DIS; PinHeader_1x06_P2.54mm_Vertical
U2: ER_OLEDM0.91_1x-I2C
U3: LM1117T-3.3; TO-220-3_Vertical
U4: MOUDLE-SEEEDUINO-XIAO; XIAO-Generic-Hybrid-14P-2.54-21X17.8MM
U5: PAM8302AAD; SOIC-8_3.9x4.9mm_P1.27mm

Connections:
+BATT: C3.1, TP1.1 (1_1), U3.3 (VI)
-BATT: C1.1, C2.1, C3.2, C4.2, C5.2, C7.2, C8.2, R3.2, RV1.3, SW1.C, SW1.S2, TP2.1 (1_1), U1.2 (VSS), U1.5 (ADDR), U2.1 (GND), U3.1 (GND), U4.13 (GND), U5.4 (IN-), U5.7 (GND)
EC11A: SW1.A, U4.1 (PA02_A0_D0)
EC11B: SW1.B, U4.2 (PA4_A1_D1)
EC11SW1: SW1.S1, U4.3 (PA10_A2_D2)
unnamed: C6.2, RV1.1
unnamed: RV1.2, U5.3 (IN+)
unnamed: TP3.1 (1_1), U5.5 (OUT+)
unnamed: TP4.1 (1_1), U5.8 (OUT-)
PWM: C6.1, R3.1, U4.10 (PA5_A9_D9_MISO)
SCL: R2.1, U1.3 (SCL), U2.3 (SCL), U4.6 (PA9_A5_D5_SCL)
SDA: R1.2, U1.4 (SDA), U2.4 (SDA), U4.5 (PA8_A4_D4_SDA)
VCC: C1.2, C2.2, C4.1, C5.1, C7.1, C8.1, R1.1, R2.2, U1.1 (VDD), U2.2 (VCC), U3.2 (VO), U4.12 (3V3), U5.6 (VDD)

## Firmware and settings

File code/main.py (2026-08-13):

"""
Code courtesy of Captain Moonlite
"""

from machine import Pin, I2C, PWM
from ssd1306 import SSD1306_I2C
import time
import sht31

#define pins
#do not use pull up/down if irl one already in place
BUTTON_PIN = Pin(28, Pin.IN, Pin.PULL_UP)
DIRECTION_PIN = Pin(26, Pin.IN, Pin.PULL_UP)
STEP_PIN = Pin(27, Pin.IN, Pin.PULL_UP)
PWM_PIN = Pin(4)

#instantiate objects
i2c = I2C(1, scl=Pin(7), sda=Pin(6), freq=400000) #freq: clock speed
oled = SSD1306_I2C(128, 32, i2c)
pwm = PWM(PWM_PIN, freq=440, duty_u16=0)
sensor = sht31.SHT31(i2c)

oled.fill(0)
oled.text("BANJOBOX", 0, 0)
oled.show()
time.sleep(2)

#more definitions :D
MODES = ["TONE", "SENSE"]
NOTES = [
    ["G4", 392.00],
    ["D3", 146.83],
    ["G3", 196.00],
    ["B3", 246.94],
    ["D4", 293.66]
]

#concerning debouncing
last_button = 0
time_last_pressed = 0
DEBOUNCE_TIME = 50

#note selection
current_note = 0
previous_note = current_note
num_notes = len(NOTES)

#mode selection
current_mode = 0
previous_mode = -1
num_modes = len(MODES)

#SHT31 read interval
READ_INTERVAL = 40
time_last_reading = time.ticks_ms()

#concerning rotary encoder
previous_value = True

#main loop
while True:
    now = time.ticks_ms()
    button = BUTTON_PIN.value()

    #clear display
    oled.fill(0)

    #tone mode
    if current_mode == 0:

        # check if mode has just been changed
        if current_mode != previous_mode:
            pwm.duty_u16(32768)
            print("playing tone")
            previous_mode = current_mode

        if previous_note != current_note: #check if note has just been changed
            #start playing tone
            pwm.freq(int(NOTES[current_note][1]))
            pwm.duty_u16(32768)
            print("playing new tone")
            previous_note = current_note

        # rotary encoder logic: check if note needs to be changed
        step = STEP_PIN.value()
        direction = DIRECTION_PIN.value()
        if previous_value != step:  # if STEP_PIN has changed
            if not step:
                if not direction:
                    print("turned left")
                    current_note -= 1 #previous note
                else:
                    print("turned right")
                    current_note += 1  #next note
                current_note %= num_notes
            previous_value = step

        oled.fill(0)
        oled.text("Tone", 0, 0)
        oled.text(NOTES[current_note][0], 0, 10)

    #sense mode
    elif current_mode == 1:
        if current_mode != previous_mode:  # check if mode has just been changed
            pwm.duty_u16(0) #stop playing tone
            print("stopped playing note")
            previous_mode = current_mode

        if time.ticks_diff(now, time_last_reading) > READ_INTERVAL:
            temp, humidity = sensor.get_temp_humi()
            print(f"Temperature: {temp}°C Humidity: {humidity}%")
            time_last_reading = now

            oled.fill(0)
            oled.text("Sense", 0, 0)
            oled.text(f"{round(temp,1)}.C {round(humidity)}%", 0, 10)

    #check if button pressed to change mode
    #button logic: True for not pressed, False for pressed
    if button and not last_button: #ie if pressed and not pressed before
        if time.ticks_diff(now, time_last_pressed) > DEBOUNCE_TIME:
            print("button pushed")
            # change mode
            current_mode = (current_mode + 1) % num_modes
            time_last_pressed = now

    last_button = button

    #update display yippee
    oled.show()

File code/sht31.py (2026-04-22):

from machine import I2C
from micropython import const
import time

R_HIGH   = const(1)
R_MEDIUM = const(2)
R_LOW    = const(3)

class SHT31(object):
    """
    This class implements an interface to the SHT31 temprature and humidity
    sensor from Sensirion.
    """

    # This static map helps keeping the heap and program logic cleaner
    _map_cs_r = {
    	True: {
            R_HIGH : b'\x2c\x06',
            R_MEDIUM : b'\x2c\x0d',
            R_LOW: b'\x2c\x10'
            },
        False: {
            R_HIGH : b'\x24\x00',
            R_MEDIUM : b'\x24\x0b',
            R_LOW: b'\x24\x16'
            }
        }

    def __init__(self, i2c, addr=0x44):
        """
        Initialize a sensor object on the given I2C bus and accessed by the
        given address.
        """
        if i2c == None:
            raise ValueError('I2C object needed as argument!')
        self._i2c = i2c
        self._addr = addr

    def _send(self, buf):
        """
        Sends the given buffer object over I2C to the sensor.
        """
        self._i2c.writeto(self._addr, buf)

    def _recv(self, count):
        """
        Read bytes from the sensor using I2C. The byte count can be specified
        as an argument.
        Returns a bytearray for the result.
        """
        return self._i2c.readfrom(self._addr, count)

    def _raw_temp_humi(self, r=R_HIGH, cs=True):
        """
        Read the raw temperature and humidity from the sensor and skips CRC
        checking.
        Returns a tuple for both values in that order.
        """
        if r not in (R_HIGH, R_MEDIUM, R_LOW):
            raise ValueError('Wrong repeatabillity value given!')
        self._send(self._map_cs_r[cs][r])
        time.sleep_ms(50)
        raw = self._recv(6)
        return (raw[0] << 8) + raw[1], (raw[3] << 8) + raw[4]

    def get_temp_humi(self, resolution=R_HIGH, clock_stretch=True, celsius=True):
        """
        Read the temperature in degree celsius or fahrenheit and relative
        humidity. Resolution and clock stretching can be specified.
        Returns a tuple for both values in that order.
        """
        t, h = self._raw_temp_humi(resolution, clock_stretch)
        if celsius:
            temp = -45 + (175 * (t / 65535))
        else:
            temp = -49 + (315 * (t / 65535))
        return temp, 100 * (h / 65535)

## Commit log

2026-04-01 started drawing schematic
    [banjobox.kicad_pcb, banjobox.kicad_sch]
2026-04-02 first draft of schematic
    [banjobox.kicad_sch]
2026-04-03 uploaded pcb workflow, copied from chatgpt. made minor change to schematic.
    [banjobox.kicad_pcb, banjobox.kicad_sch]
2026-04-04 completed drawing schematic
    [banjobox.kicad_sch]
2026-04-04 rearranged files
    [banjobox.kicad_pcb, banjobox.kicad_sch]
2026-04-06 added voltage regulator to schematic and finished assigning footprints
    [banjobox.kicad_pcb, banjobox.kicad_sch, freerouting.dsn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]
2026-04-08 removed R pin from SHT31 to better suit breakout board
    [banjobox.kicad_pcb, banjobox.kicad_sch]
2026-04-08 assigned new footprints (pinheader) and more progress on pcb
    [banjobox.kicad_pcb, banjobox.kicad_sch]
2026-04-09 routed pcb
    [banjobox.kicad_sch]
2026-04-09 forgot to save after last commit, routed pcb
    [banjobox.kicad_pcb]
2026-04-15 added bird graphic to pcb and added some silkscreen labels
    [banjobox.kicad_pcb]
2026-04-15 pcb added all silkscreen text
    [banjobox.kicad_pcb]
2026-04-16 updated 3d models for pcb footprints
    [banjobox.kicad_pcb]
2026-04-21 implemented encoder logic
2026-04-25 created BOM
2026-04-30 added images
    [banjobox.kicad_pcb]
2026-04-30 deleted code folder uneeded
    [banjobox-B_Cu.gbl, banjobox-B_Mask.gbs, banjobox-B_Paste.gbp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]
2026-04-30 wire route
    [banjobox.kicad_pcb]
2026-05-01 uploaded step and dxf files to production
    [knob.step, pcb_cover.dxf, pcb_cover_mounts.step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]
2026-05-04 re added bom
2026-05-04 removed tracking for backups etc
    [banjobox-B_Cu.gbl, banjobox-B_Mask.gbs, banjobox-B_Paste.gbp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]
2026-05-20 exported edited cad models
    [pcb_cover.dwg, pcb_cover.dxf, speaker_cover.dwg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]
2026-05-20 file organisation
    [knob.step, knob.stl, pcb_cover_mounts.step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]
2026-08-11 rotary encoder and oled working
2026-08-11 tidied repo
    [banjobox.kicad_pcb, banjobox.kicad_sch, freerouting.dsn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]
2026-08-16 update readme
    Updated instructions for battery holder attachment and added notes about PCB changes.
2026-08-22 better schematic jpeg
2026-08-22 Change schematic image extension to .jpg
    Updated schematic image file extension from .jpeg to .jpg.
